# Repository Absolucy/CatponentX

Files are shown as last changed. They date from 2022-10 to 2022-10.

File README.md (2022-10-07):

# CatponentX

This is a board that, in theory, allows for high quality component video output from the original Xbox. It replaces the AV Port, with a PCB that sticks out the back, providing high-quality analog video and digital audio output.

## Installation Instructions

These have only been tested on Xbox 1.0! Pads may differ on later Xbox revisions. 
Although, they should be the same on 1.1, but I believe 1.2-1.4 and 1.6 have different encoders, and likely a different board layout in that area.

### Y/Pb/Pr wires

(need an image)
1. Remove the inductors at L4A2, L4A3, and L4A3. They are above the video encoder, near the AV port. They're black and blue, and very big. Should be easy to remove with low-melt solder.
2. Solder 3 wires to the *bottom* pads (the one facing the video encoder chip). They should be long enough to go out the AV port. I personally used [this 3-core shielded wire](https://amazon.com/gp/product/B01LNH8POQ), to reduce interference.
3. Solder those wires to the Y/Pb/Pr pads on the CatponentX chip. I honestly forgot which one was which, so uh, if someone could figure that out, that'd be great.

### AV Port wires

You will need to solder 3 wires (5V, GND, and S/PDIF) to the A/V port holes here. They go to the appropiately labeled pads on the CatponentX PCB. Shielding is not needed.

You will also need to solder two jumpers between the Mode 2/Mode 3 holes, and the adjacent ground points. (Technically, ground is ground and it doesn't matter which ground you use, but it's just convienent to use the adjacent ground pins)

5V = Red  
GND = Black  
Green = S/PDIF  
Mode 2 = Dark Blue (solder to ground)  
Mode 3 = Light Blue (solder to ground)  
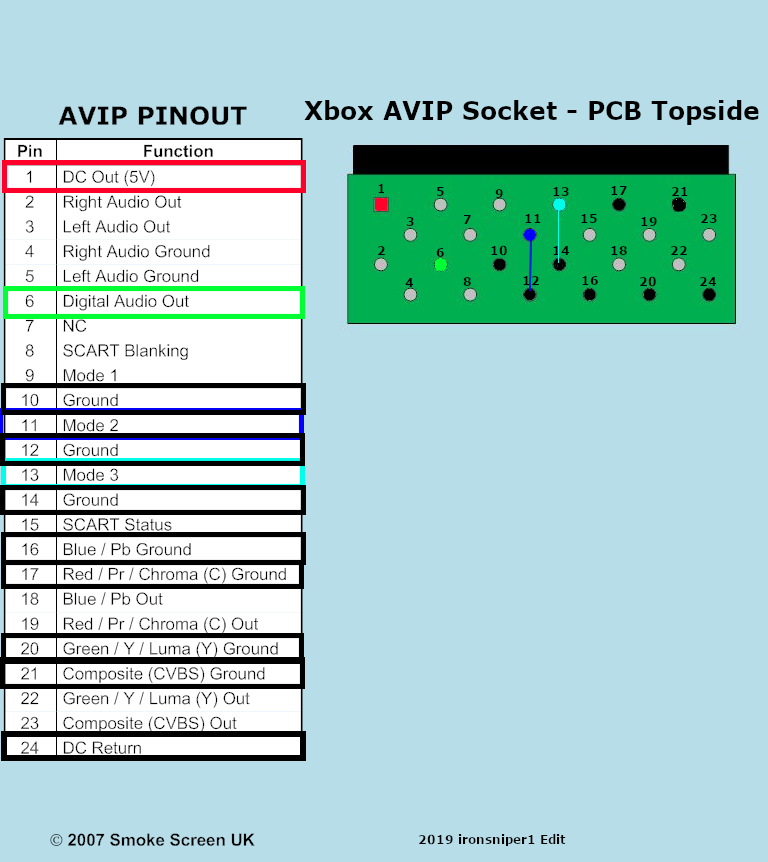
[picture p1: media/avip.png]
AVIP Port Diagram


## Bill of Materials

| **References** | **Part Description** | **Quanity** | **Price (Total)** | **Digi-Key** |
| --- | --- | --- | --- | --- |
| C1 | 10uF 16V Aluminum Capacitor | 1 | $0.56 | [493-3913-1-ND](https://www.digikey.com/en/products/detail/nichicon/UCL1C100MCL1GS/2300262) |
| C2, C3 | 0.1uF 100V Ceramic Capacitor | 1 | $0.20 | [1276-6840-1-ND](https://www.digikey.com/en/products/detail/samsung-electro-mechanics/CL21B104KCFNNNE/5961324) |
| R1, R2, R3 | 75 Ohm 1/8W 0805 Resistor | 3 | $0.30 | [CR0805-FX-75R0ELFCT-ND](https://www.digikey.com/en/products/detail/bourns-inc/CR0805-FX-75R0ELF/3740954) |
| R4 | 160 Ohm 1/8W 0805 Resistor | 1 | $0.10 | [118-CR0805-FX-1600ELFCT-ND](https://www.digikey.com/en/products/detail/bourns-inc/CR0805-FX-1600ELF/3784671) |
| LED1 | Diffused Red 2V LED | 1 | $0.39 | [754-1901-ND](https://www.digikey.com/en/products/detail/kingbright/WP914IDT) |
| FILTER1 | THS7316DR Analog Video Filter/Amp | 1 | $1.01 | [296-26684-1-ND](https://www.digikey.com/en/products/detail/texas-instruments/THS7316DR/1905373) |
| RCA1 | 3 Component RCA Jacks | 1 | $2.56 | [SC1854-ND](https://www.digikey.com/en/products/detail/switchcraft-inc/PJRAN3X1U03X/1288816) |
| TOSLINK1 | Optical S/PDIF Transmitter | 1 | N/A | [3185-FCR684208T-ND](https://www.digikey.com/en/products/detail/cliff-electronic-components-ltd/FCR684208T/15283099) |

**Note**: R4 and LED1 are optional if you don't want a power LED.

## Known Issues

- Video seems too bright (@Absolucy)
- S/PDIF output doesn't work for me (@Absolucy)

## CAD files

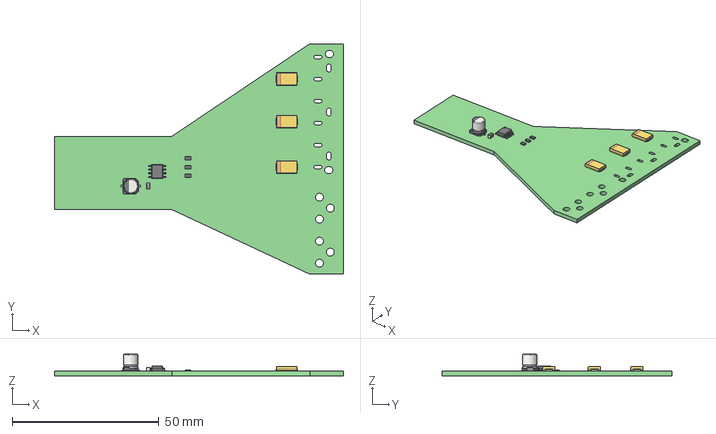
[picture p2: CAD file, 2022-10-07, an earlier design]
CatponentX [rev1, old].step
98.5 x 78.5 x 7.45 mm
CatponentX [rev1, old] PCB

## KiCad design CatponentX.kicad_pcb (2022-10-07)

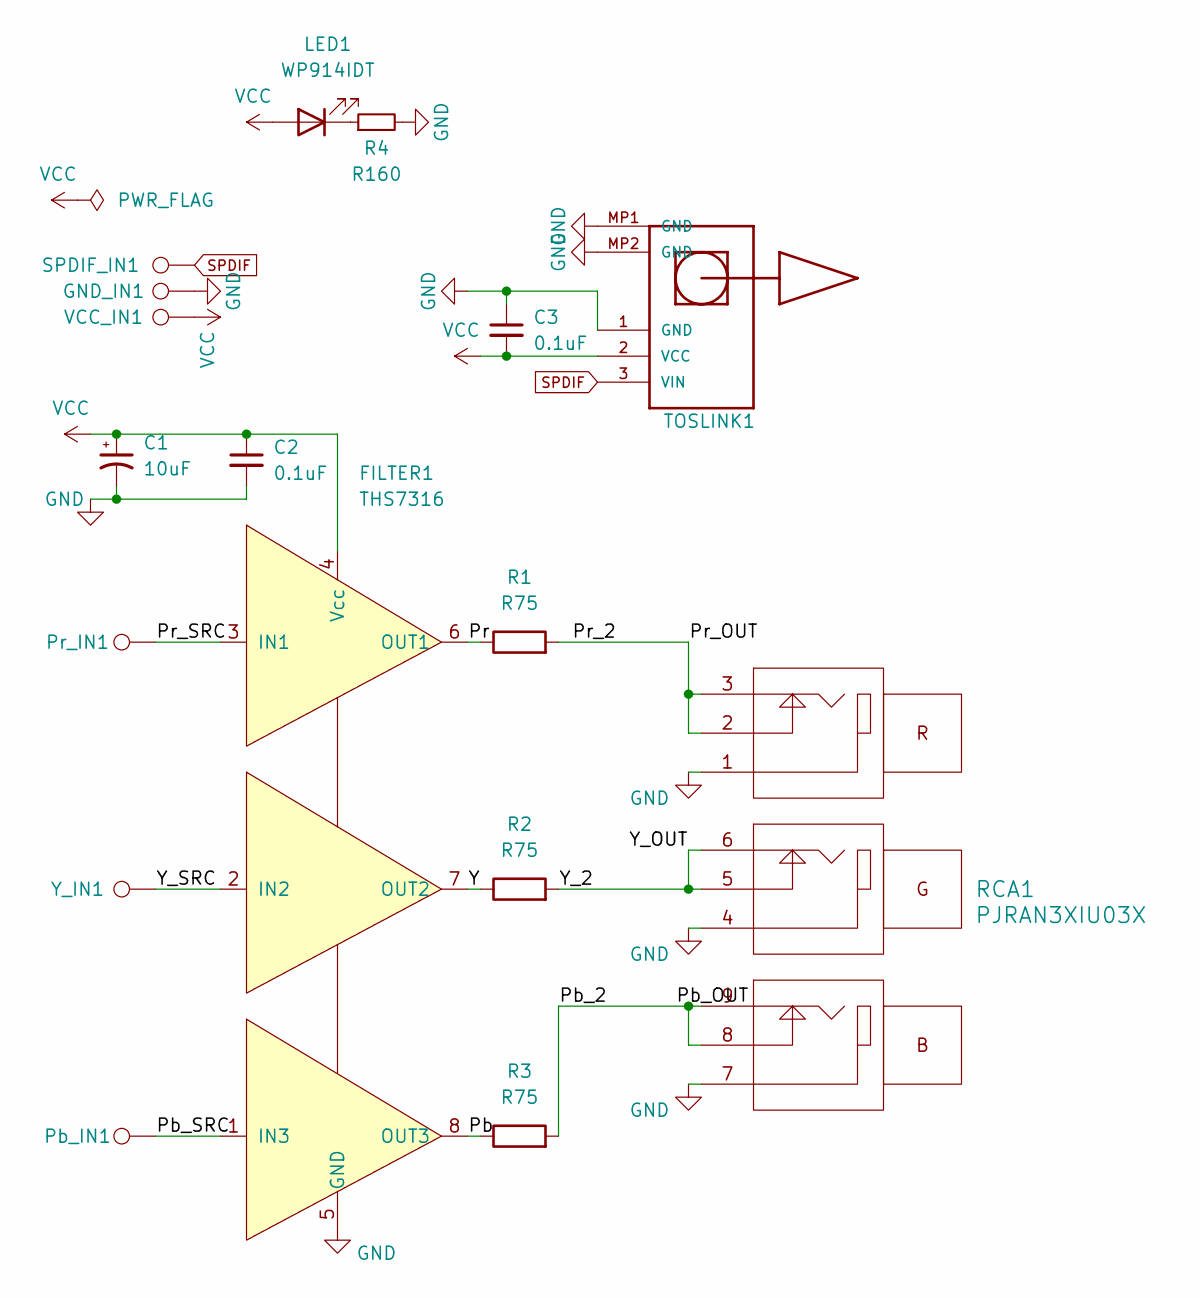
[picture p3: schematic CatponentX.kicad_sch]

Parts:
C1: 10uF; CP_Elec_5x5.8; Manufacturer Part Number UCL1C100MCL1GS; Digi-Key Part Number 493-3913-1-ND
C2, C3: 0.1uF; C_0805_2012Metric_Pad1.18x1.45mm_HandSolder; Manufacturer Part Number CL21B104KCFNNNE; Digi-Key Part Number 1276-6840-1-ND
FILTER1: THS7316; Manufacturer Part Number THS7316DR; Digi-Key Part Number 296-26684-1-ND
GND_IN1: Y_IN; TestPoint_Pad_D2.5mm
LED1: WP914IDT; LED_D3.0mm; Manufacturer Part Number WP914IDT; Digi-Key Part Number 754-1901-ND
Pb_IN1: Pr_IN; TestPoint_Pad_D2.5mm
Pr_IN1: Y_IN; TestPoint_Pad_D2.5mm
R1, R2, R3: R75; R_0805_2012Metric_Pad1.20x1.40mm_HandSolder; Manufacturer Part Number CR0805-FX-75R0ELF; Digi-Key Part Number CR0805-FX-75R0ELFCT-ND
R4: R160; R_0805_2012Metric_Pad1.20x1.40mm_HandSolder; Manufacturer Part Number CR0805-FX-1600ELF; Digi-Key Part Number 118-CR0805-FX-1600ELFCT-ND
RCA1: PJRAN3XIU03X; PJRAN3X1U; Manufacturer Part Number PJRAN3X1U03X; Digi-Key Part Number SC1854-ND
SPDIF_IN1: Y_IN; TestPoint_Pad_D2.5mm
TOSLINK1: FCR684208T; FCR684205T
VCC_IN1: Y_IN; TestPoint_Pad_D2.5mm
Y_IN1: Pb_IN; TestPoint_Pad_D2.5mm

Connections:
/Pb: FILTER1.8 (OUT3), R3.1
/Pb_2: R3.2, RCA1.8, RCA1.9
/Pb_SRC: FILTER1.1 (IN3), Pb_IN1.1
/Pr: FILTER1.6 (OUT1), R1.1
/Pr_2: R1.2, RCA1.2, RCA1.3
/Pr_SRC: FILTER1.3 (IN1), Pr_IN1.1
/Y: FILTER1.7 (OUT2), R2.1
/Y_2: R2.2, RCA1.5, RCA1.6
/Y_SRC: FILTER1.2 (IN2), Y_IN1.1
GND: C1.2, C2.2, C3.1, FILTER1.5 (GND), GND_IN1.1, R4.2, RCA1.1, RCA1.4, RCA1.7, TOSLINK1.1 (GND), TOSLINK1.MP1 (GND), TOSLINK1.MP2 (GND)
unnamed: LED1.1 (K), R4.1
SPDIF: SPDIF_IN1.1, TOSLINK1.3 (VIN)
VCC: C1.1, C2.1, C3.2, FILTER1.4 (Vcc), LED1.2 (A), TOSLINK1.2 (VCC), VCC_IN1.1

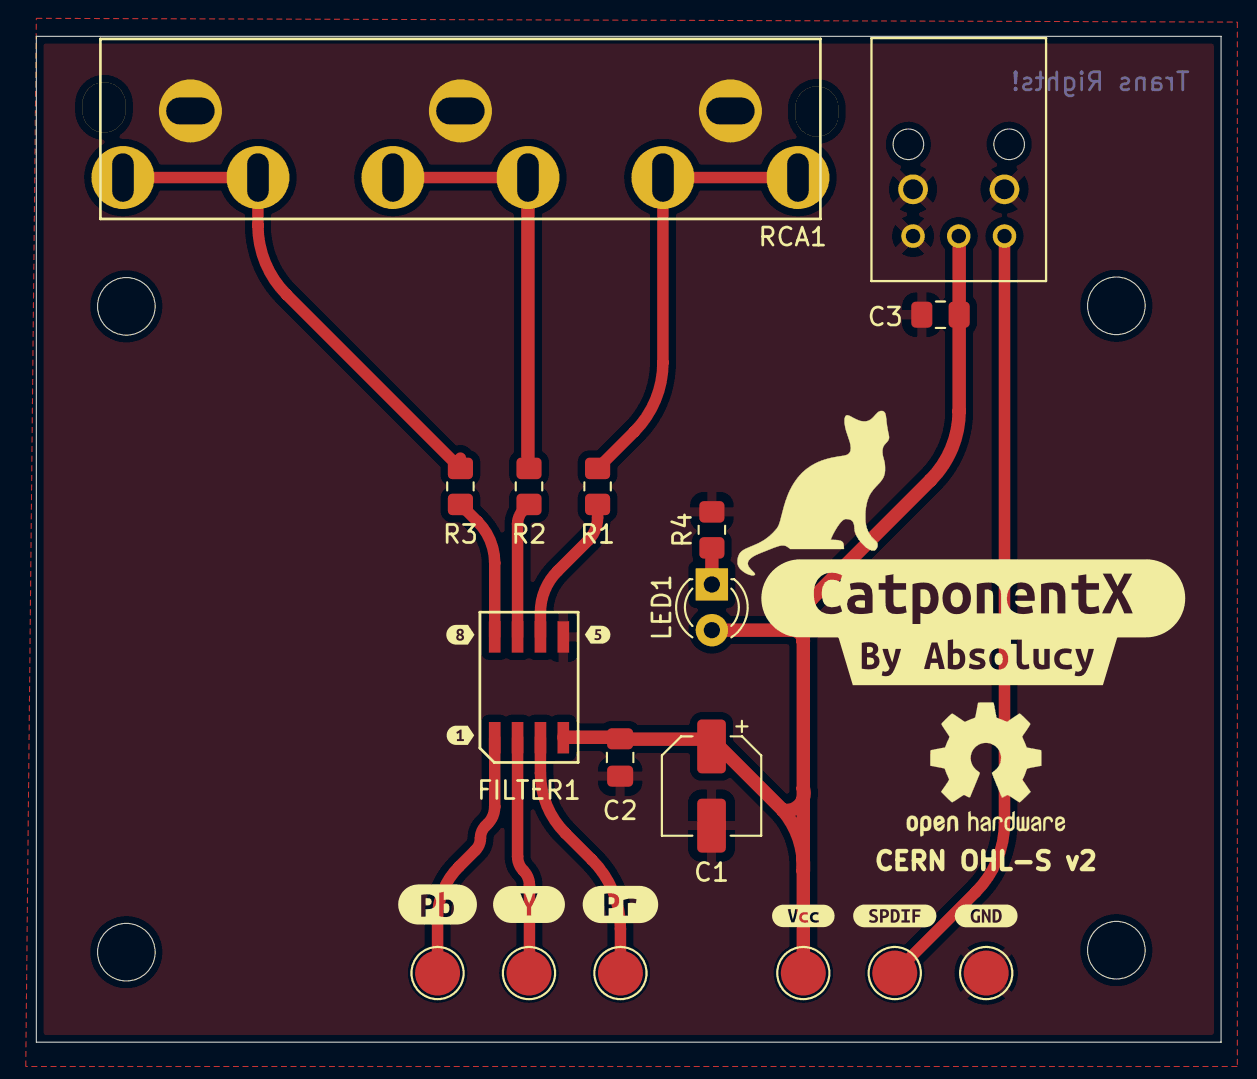
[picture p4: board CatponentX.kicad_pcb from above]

Board: 2 copper layers, 65.8 x 55.9 mm, 28 parts (0 on the bottom side), 13 nets.

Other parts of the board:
kibuzzard-630BAD88: G***; kibuzzard-630BAD88
kibuzzard-630BAD90: G***; kibuzzard-630BAD90
kibuzzard-630C1A0C: G***; kibuzzard-630C1A0C
kibuzzard-630C1A19: G***; kibuzzard-630C1A19
kibuzzard-630C1A27: G***; kibuzzard-630C1A27
kibuzzard-630D7263: G***; kibuzzard-630D7263
kibuzzard-630D7269: G***; kibuzzard-630D7269
kibuzzard-630E2579: G***; kibuzzard-630E2579
kibuzzard-6303C26E: G***; kibuzzard-6303C26E
kibuzzard-6303C228: G***; kibuzzard-6303C228
kibuzzard-6303C288: G***; kibuzzard-6303C288

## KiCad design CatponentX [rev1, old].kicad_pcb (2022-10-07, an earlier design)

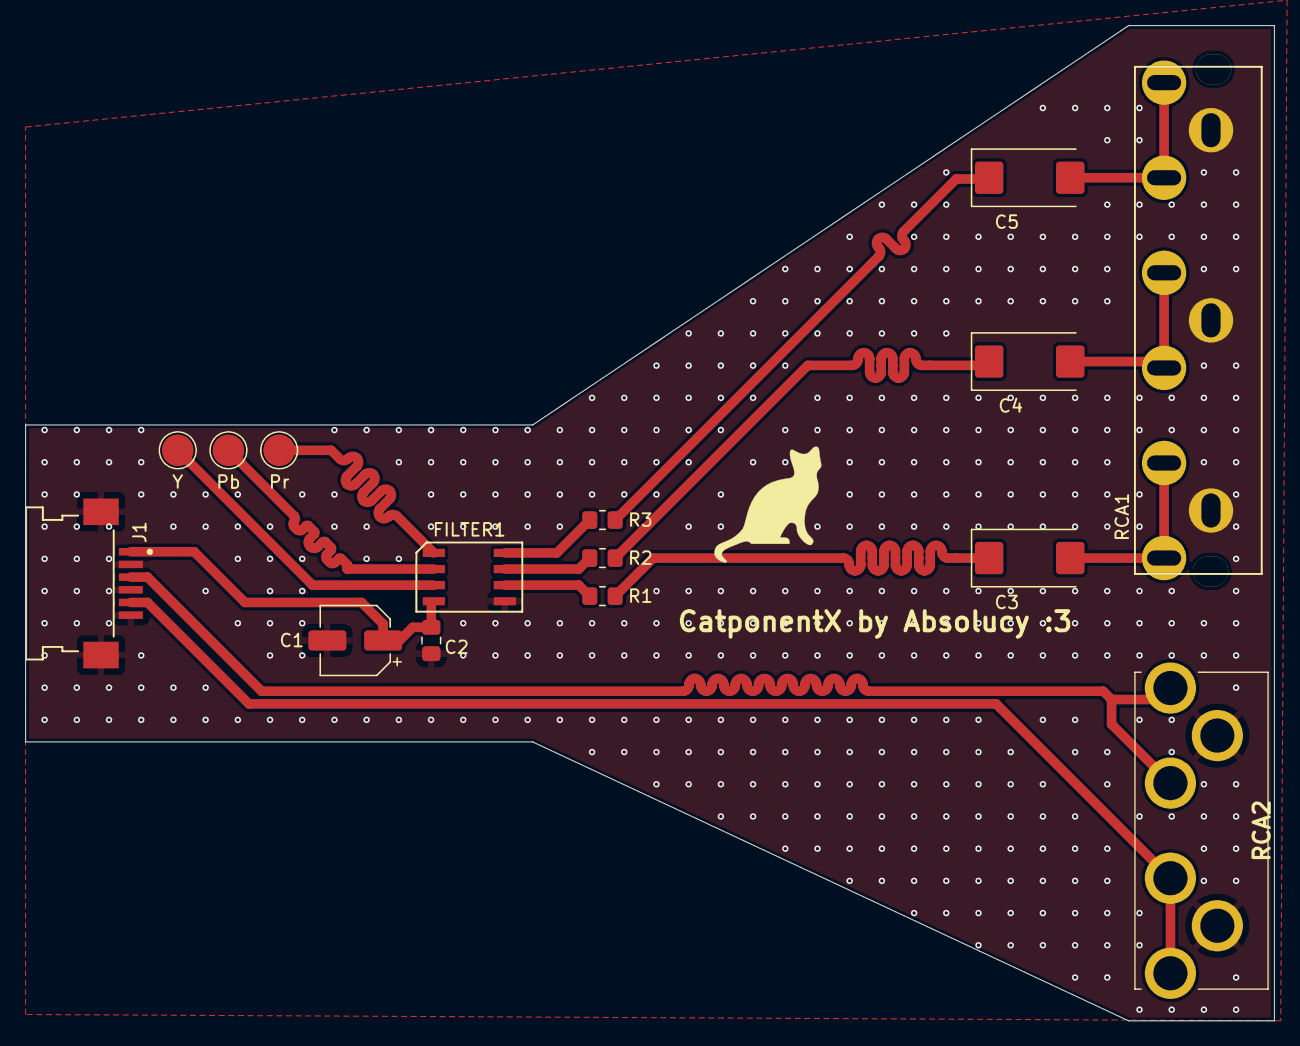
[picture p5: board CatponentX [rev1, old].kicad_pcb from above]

Board: 2 copper layers, 98.5 x 78.5 mm, 15 parts (0 on the bottom side), 16 nets.

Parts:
C1: 10uF; CP_Elec_5x5.8
C2: 0.1uF; C_0805_2012Metric_Pad1.18x1.45mm_HandSolder
C3, C4, C5: 220uF; CP_EIA-7343-15_Kemet-W_Pad2.25x2.55mm_HandSolder
FILTER1: THS7316
J1: 52207-0660; Molex-52207-0660
Pb: Pb_SRC; TestPoint_Pad_D2.5mm
Pr: Pr_SRC; TestPoint_Pad_D2.5mm
R1, R2, R3: R75; R_0805_2012Metric_Pad1.20x1.40mm_HandSolder
RCA1: PJRAN3XIU03X; PJRAN3X1U
RCA2: PJRAN2X1U01AUX
Y: Y_SRC; TestPoint_Pad_D2.5mm

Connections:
/Pb: FILTER1.7 (OUT2), R2.1
/Pb_2: C4.1, R2.2
/Pb_OUT: C4.2, RCA1.5, RCA1.6
/Pb_SRC: FILTER1.2 (IN2), Pb.1
/Pr: FILTER1.8 (OUT3), R3.1
/Pr_2: C5.1, R3.2
/Pr_OUT: C5.2, RCA1.8, RCA1.9
/Pr_SRC: FILTER1.1 (IN3), Pr.1
/Y: FILTER1.6 (OUT1), R1.1
/Y_2: C3.1, R1.2
/Y_OUT: C3.2, RCA1.2, RCA1.3
/Y_SRC: FILTER1.3 (IN1), Y.1
Audio_L: J1.5, RCA2.2, RCA2.3
Audio_R: J1.3, RCA2.5, RCA2.6
GND: C1.2, C2.2, FILTER1.5 (GND), J1.2, J1.4, J1.6, J1.MP1, J1.MP2, RCA1.1, RCA1.4, RCA1.7, RCA2.1, RCA2.4
VCC: C1.1, C2.1, FILTER1.4 (Vcc), J1.1

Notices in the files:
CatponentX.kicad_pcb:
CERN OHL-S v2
